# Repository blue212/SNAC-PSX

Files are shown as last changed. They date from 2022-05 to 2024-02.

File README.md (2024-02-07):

# SNAC
PSX Accessory converter for MiSTer, by blue212

Serial Native Accessory Converter

SNAC adapter for PSX. This board and psx use 3v3 logic. This is a standalone board, so it's not to used with the SNAC level shifter board. You can use a short male to female usb3.0 extension cable between it and misters USER port.

It has two ports for controllers and a composite port for guncon, also has a header for test points. If a guncon is connected and a justifier isn't the needed signal for Guncon will be output through the composite port.

This version has a solder jumper to connect 5v to the 7.6v pin for rumble. You could not solder the jumper and add external power, but be advised that bad things will happen if you mix up polarity.

-TODO 

-Updates

Added Memory Card add-on board. It uses a 0.8mm thick pcb.

Added files for 3D print cases. Designed by [DiniertoDesigns](https://www.thingiverse.com/thing:5530398)

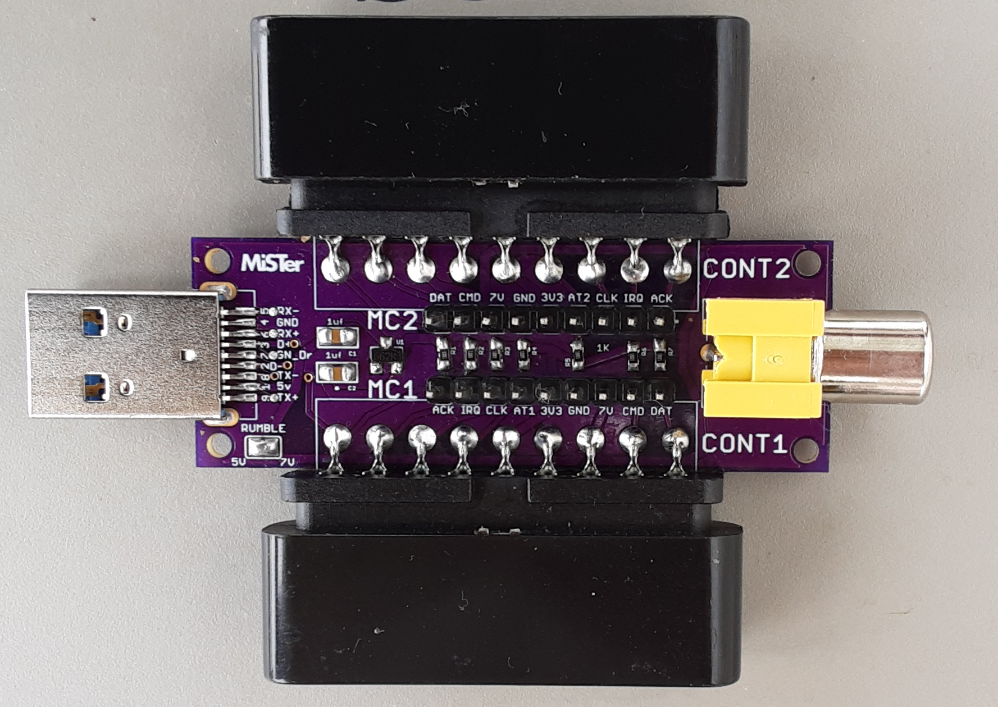
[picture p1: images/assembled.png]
ASEMBLED


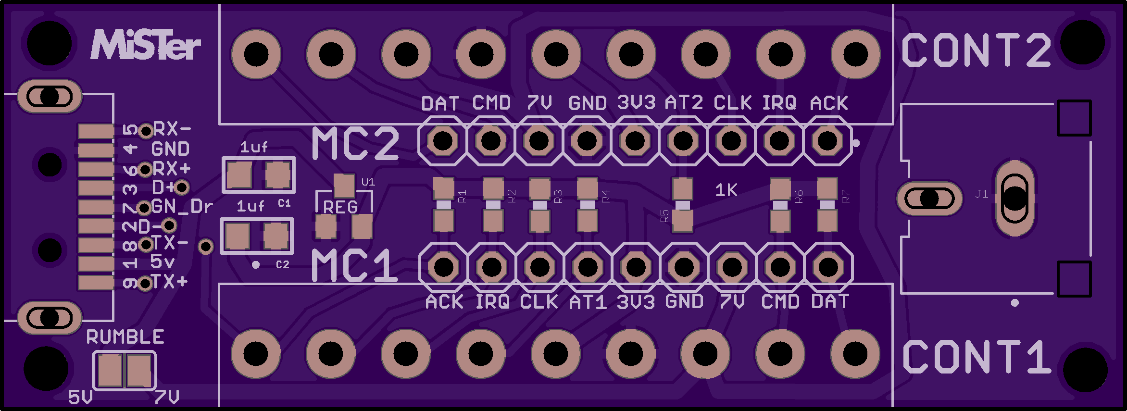
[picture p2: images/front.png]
FRONT


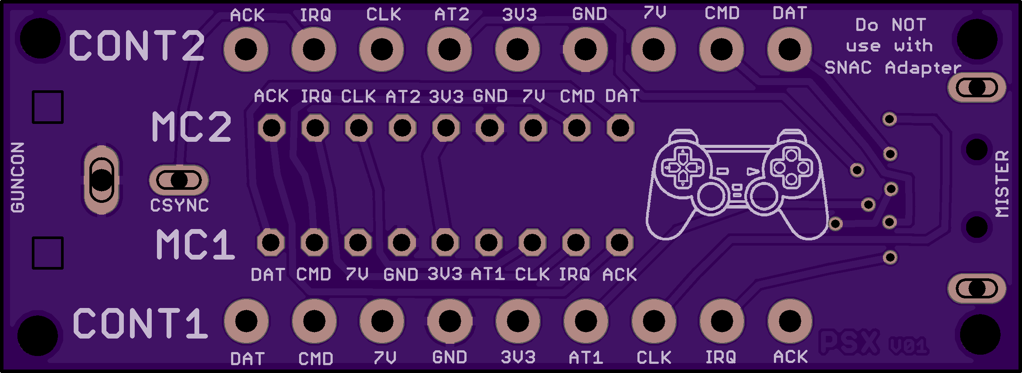
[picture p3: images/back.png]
BACK


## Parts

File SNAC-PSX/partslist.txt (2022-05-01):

Part  Value                          Device                         Package      Description                                                             AVAILABILITY COMMENT CUI_PURCHASE_URL                                                                                                                                           DESCRIPTION                                                MF              MP      PACKAGE PRICE  PURCHASE-URL                                            
C1    1uf                            C_0805                         C0805        NON-POLARIZED CAP                                                                                                                                                                                                                                                                                                                                                                                                 
C2    1uf                            C_0805                         C0805        NON-POLARIZED CAP                                                                                                                                                                                                                                                                                                                                                                                                 
CONT1 PS2                            PS2                            TE_PS2       Check prices                                                            In Stock     PS2                                                                                                                                                                 Connector Header Through Hole 9 position 0.156 (3.96mm)   TE Connectivity PS2     None    None   https://pricing.snapeda.com/search/part/PS2/?ref=eda    
CONT2 PS2                            PS2                            TE_PS2       Check prices                                                            In Stock     PS2                                                                                                                                                                 Connector Header Through Hole 9 position 0.156 (3.96mm)   TE Connectivity PS2     None    None   https://pricing.snapeda.com/search/part/PS2/?ref=eda    
J1    RCJ-044                        RCJ-044                        CUI_RCJ-044  Metal Right-Angle, RCA Jack, Yellow Housing and Insulation Check prices In Stock             https://www.cuidevices.com/product/interconnect/connectors/rca-connectors/rcj-04-series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 Metal Right-Angle, RCA Jack, Yellow Housing and Insulation CUI Devices     RCJ-044 None    None   https://pricing.snapeda.com/search/part/RCJ-044/?ref=eda
K2    692112030100                   692112030100                   692112030100 WR-COM  USB 3.0 SMT PLUG WITH CLIPTYPE A                                                                                                                                                                                                                                                                                                                                                                          
MC1                                  PINHD-1X09_2.54-S              1X09-S       PIN HEADER                                                                                                                                                                                                                                                                                                                                                                                                        
MC2                                  PINHD-1X09_2.54-S              1X09-S       PIN HEADER                                                                                                                                                                                                                                                                                                                                                                                                        
R1    1K                             RESISTOR0603-RES               0603-RES     Resistor                                                                                                                                                                                                                                                                                                                                                                                                          
R2    1K                             RESISTOR0603-RES               0603-RES     Resistor                                                                                                                                                                                                                                                                                                                                                                                                          
R3    1K                             RESISTOR0603-RES               0603-RES     Resistor                                                                                                                                                                                                                                                                                                                                                                                                          
R4    1K                             RESISTOR0603-RES               0603-RES     Resistor                                                                                                                                                                                                                                                                                                                                                                                                          
R5    1K                             RESISTOR0603-RES               0603-RES     Resistor                                                                                                                                                                                                                                                                                                                                                                                                          
R6    1K                             RESISTOR0603-RES               0603-RES     Resistor                                                                                                                                                                                                                                                                                                                                                                                                          
R7    1K                             RESISTOR0603-RES               0603-RES     Resistor                                                                                                                                                                                                                                                                                                                                                                                                          
SJ1                                  SJ                             SJ           SMD solder JUMPER                                                                                                                                                                                                                                                                                                                                                                                                 
U1    PMIC-LDO-XC6206P332MR-G(SOT23) PMIC-LDO-XC6206P332MR-G(SOT23) SOT-23       310030099 

alternate K2
K2       a19032000ux0260               a19032000ux0260              Uxcell

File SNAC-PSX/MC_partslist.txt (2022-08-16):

Partlist

EAGLE Version 7.7.0 Copyright (c) 1988-2016 CadSoft

Assembly variant: 

Part     Value           Package             Library         Position (inch)       Orientation

J1       009155002201006 AVX_009155002201006 009155002201006 (0.924 0.16)          R180
J2       009155003201006 AVX_009155003201006 009155003201006 (0.607 0.16)          R180
J3       009155003201006 AVX_009155003201006 009155003201006 (0.199 0.16)          R180
J4       009155002201006 AVX_009155002201006 009155002201006 (0.08989764 1.22992126) R0
J5       009155003201006 AVX_009155003201006 009155003201006 (0.40643307 1.23031496) R0
J6       009155003201006 AVX_009155003201006 009155003201006 (0.81430709 1.23031496) R0
MC       PPPC091LFBN-RC  PPPC091LFBN-RC      Sullins         (0.497 0.564)         R0
MC1      PPPC091LFBN-RC  PPPC091LFBN-RC      Sullins         (0.495 0.82616535)    R180

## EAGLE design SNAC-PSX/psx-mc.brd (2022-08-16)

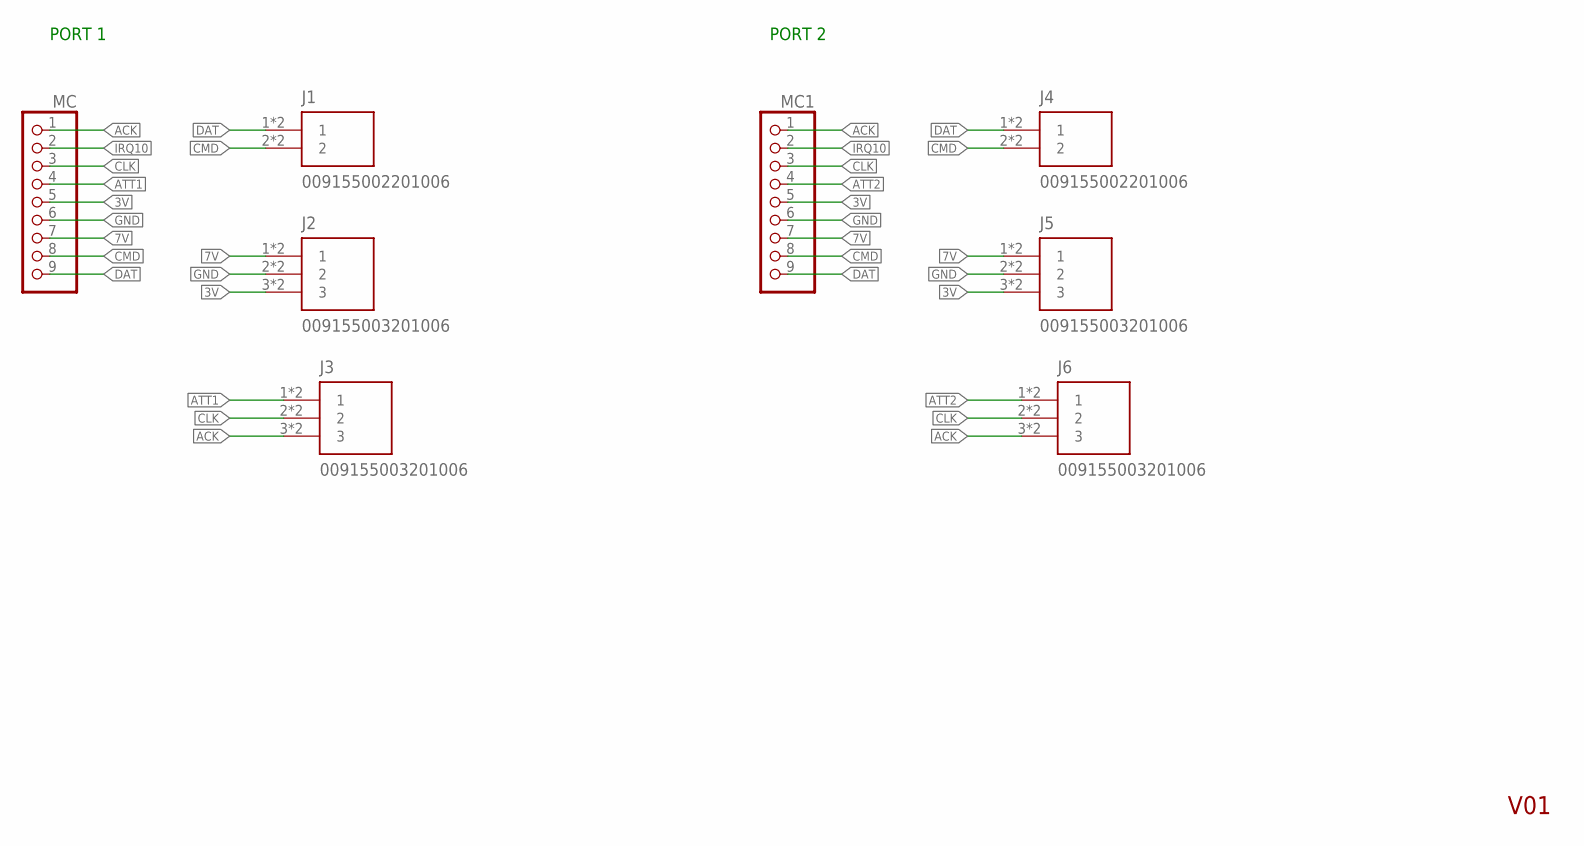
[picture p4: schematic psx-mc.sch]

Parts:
J1, J4: 009155002201006; AVX_009155002201006
J2, J3, J5, J6: 009155003201006; AVX_009155003201006
MC, MC1: PINHD-1X09_2.54-S; 1X09-S

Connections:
3V: J2.3, J2.3_1 (3), J5.3, J5.3_1 (3), MC.5, MC1.5
7V: J2.1, J2.1_1 (1), J5.1, J5.1_1 (1), MC.7, MC1.7
ACK: J3.3, J3.3_1 (3), J6.3, J6.3_1 (3), MC.1, MC1.1
ATT1: J3.1, J3.1_1 (1), MC.4
ATT2: J6.1, J6.1_1 (1), MC1.4
CLK: J3.2, J3.2_1 (2), J6.2, J6.2_1 (2), MC.3, MC1.3
CMD: J1.2, J1.2_1 (2), J4.2, J4.2_1 (2), MC.8, MC1.8
DAT: J1.1, J1.1_1 (1), J4.1, J4.1_1 (1), MC.9, MC1.9
GND: J2.2, J2.2_1 (2), J5.2, J5.2_1 (2), MC.6, MC1.6
IRQ10: MC.2, MC1.2

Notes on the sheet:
V01
PORT 1
PORT 2

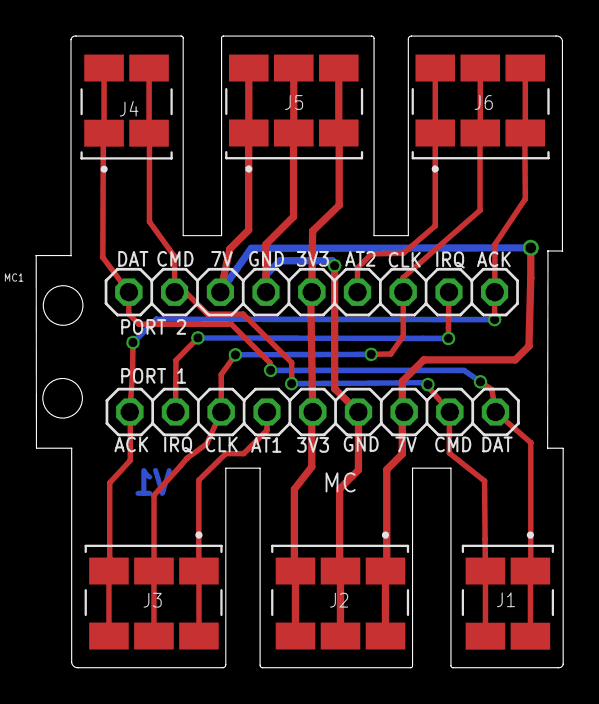
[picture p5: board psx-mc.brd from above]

Board: 2 copper layers, 29.3 x 35.1 mm, 8 parts (0 on the bottom side), 10 nets.

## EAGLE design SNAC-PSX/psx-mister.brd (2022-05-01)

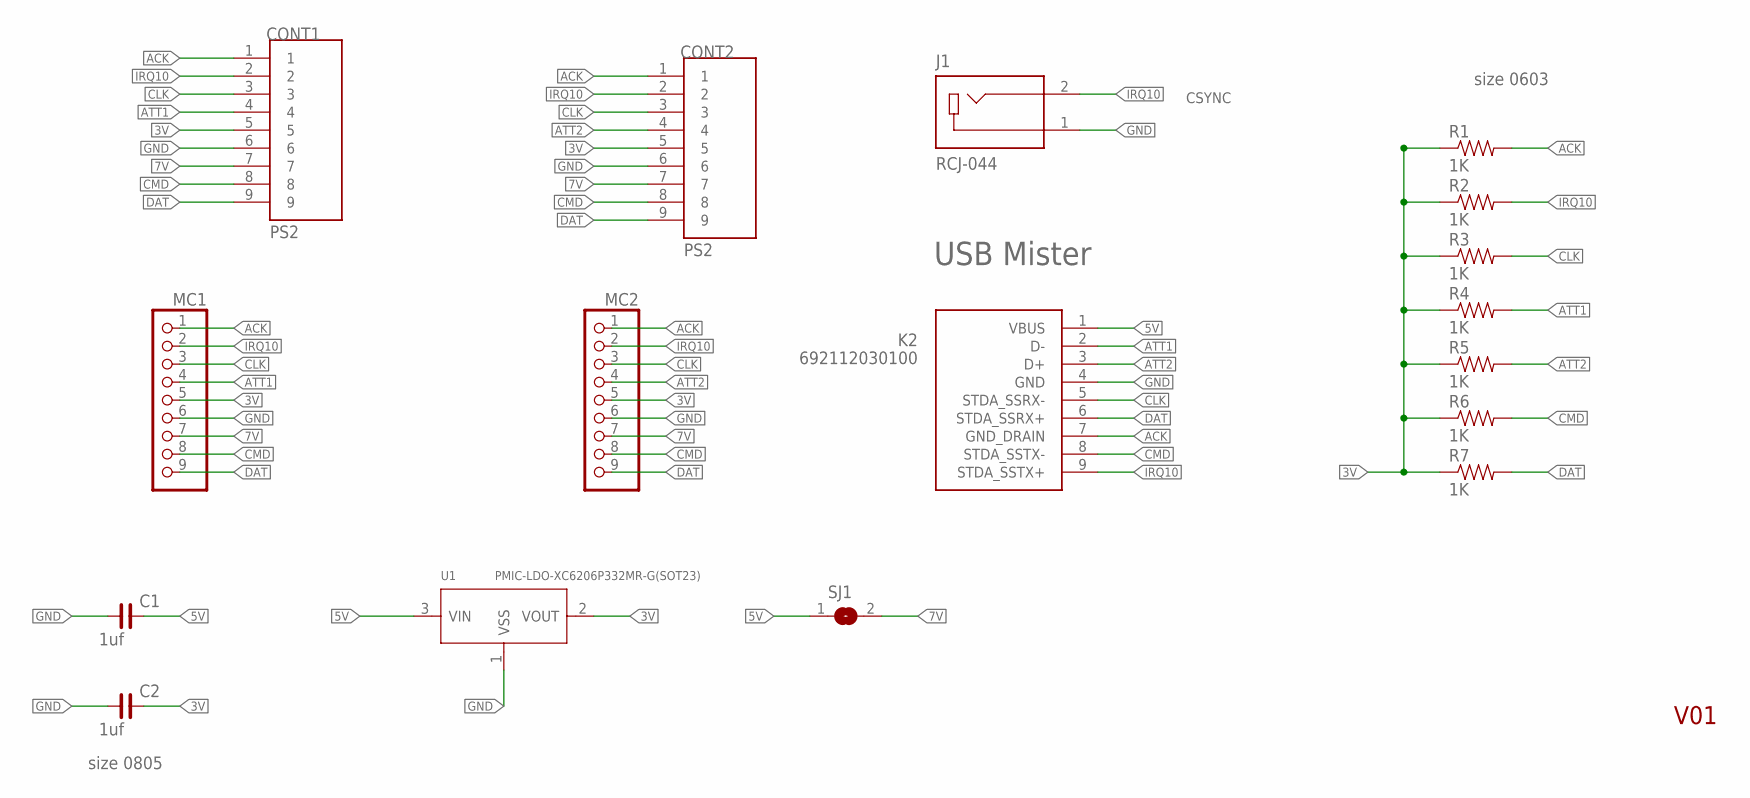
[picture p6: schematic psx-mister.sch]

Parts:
C1, C2: 1uf; C0805
CONT1, CONT2: PS2; TE_PS2
J1: RCJ-044; CUI_RCJ-044
K2: 692112030100
MC1, MC2: PINHD-1X09_2.54-S; 1X09-S
R1, R2, R3, R4, R5, R6, R7: 1K; 0603-RES
SJ1: SJ
U1: PMIC-LDO-XC6206P332MR-G(SOT23); SOT-23

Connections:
3V: C2.2, CONT1.5, CONT2.5, MC1.5, MC2.5, R1.1, R2.1, R3.1, R4.1, R5.1, R6.1, R7.1, U1.2 (VOUT)
5V: C1.2, K2.1 (VBUS), SJ1.1, U1.3 (VIN)
7V: CONT1.7, CONT2.7, MC1.7, MC2.7, SJ1.2
ACK: CONT1.1, CONT2.1, K2.7 (GND_DRAIN), MC1.1, MC2.1, R1.2
ATT1: CONT1.4, K2.2 (D-), MC1.4, R4.2
ATT2: CONT2.4, K2.3 (D+), MC2.4, R5.2
CLK: CONT1.3, CONT2.3, K2.5 (STDA_SSRX-), MC1.3, MC2.3, R3.2
CMD: CONT1.8, CONT2.8, K2.8 (STDA_SSTX-), MC1.8, MC2.8, R6.2
DAT: CONT1.9, CONT2.9, K2.6 (STDA_SSRX+), MC1.9, MC2.9, R7.2
GND: C1.1, C2.1, CONT1.6, CONT2.6, J1.1, K2.4 (GND), MC1.6, MC2.6, U1.1 (VSS)
IRQ10: CONT1.2, CONT2.2, J1.2, K2.9 (STDA_SSTX+), MC1.2, MC2.2, R2.2

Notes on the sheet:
V01
USB Mister
size 0805
CSYNC
size 0603

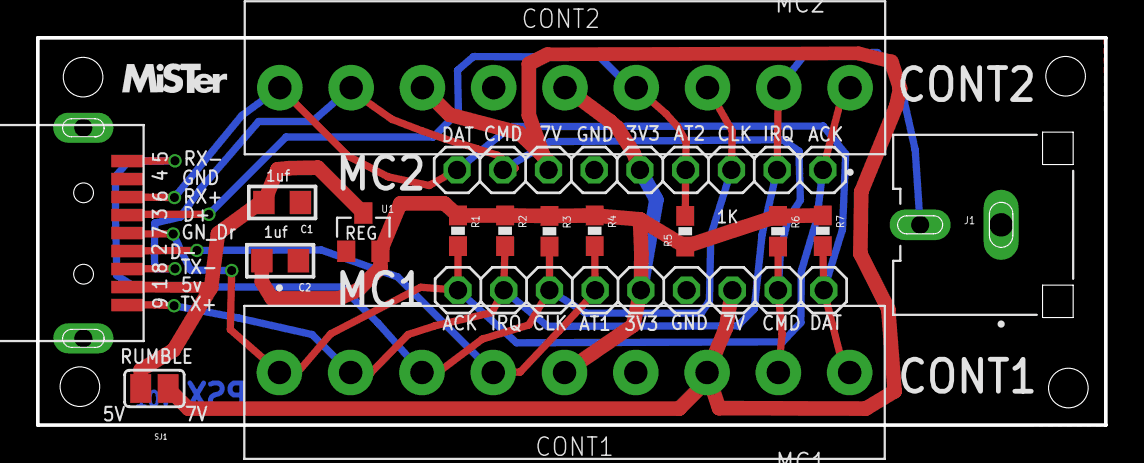
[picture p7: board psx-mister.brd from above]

Board: 2 copper layers, 59.3 x 21.5 mm, 17 parts (0 on the bottom side), 11 nets.

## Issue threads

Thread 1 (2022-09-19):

5V

neogeo81, 2022-09-19:
What happens if you use it with already 5V port like on the Multisystem? I heard it works and the rumble is better but does it damage the adapter?

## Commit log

2022-05-01 PSX SNAC
    first test version
    [psx-mister.brd, psx-mister.sch]
2022-08-16 Add Memory Card PCB
    optional add on board
    [psx-mc.brd, psx-mc.sch]
2024-02-07 added case

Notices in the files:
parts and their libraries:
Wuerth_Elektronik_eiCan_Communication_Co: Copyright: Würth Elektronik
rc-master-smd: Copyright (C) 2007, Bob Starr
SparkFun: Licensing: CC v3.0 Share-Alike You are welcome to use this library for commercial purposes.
